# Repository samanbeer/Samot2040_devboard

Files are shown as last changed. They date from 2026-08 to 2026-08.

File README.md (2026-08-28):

# SamotPi2040 DevBoard



---

## 📌 Project Overview & Purpose

- **What is it?** A standalone development board based on the Raspberry Pi RP2040 dual-core ARM Cortex-M0+ processor.
- **What does it do?** It provides all essential supporting circuitry (power regulation, Li-Po 3.7V battery charging, automatic power source switching, high-speed crystal oscillator, SPI flash, USB termination, and ESD/pull-down configuration) to run MicroPython, CircuitPython, Arduino, or bare-metal C/C++ Pico SDK code.
- **Why does it exist?** It was created to explore custom PCB design from scratch, master 2-layer routing with fine-pitch QFN and 0402 components, and build a reliable, inexpensive, and customizable devboard for prototyping robotics and embedded electronics.

---

## Why I Made This Project

Because I wanted to design my own RP2040 board with my own design a to be able to say "I made this" with:
1. A modern **USB-C** connector
2. Integrate both **BOOT** and **RESET** switches directly on board to make flashing easy.
3. Provide a full 8MB high-speed SPI Flash storage for large CircuitPython scripts, assets, and datalogging.
4. Integrated **Li-Po 3.7V battery charging** (MCP73831) and **automatic power source switching** (BAT54C Schottky diode) for portable projects.

---

## Project Gallery

### 3D Render
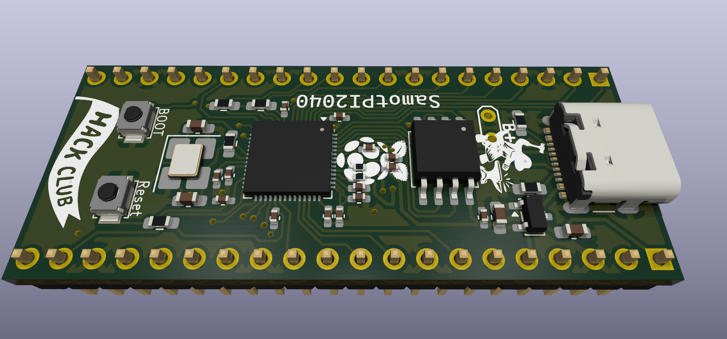
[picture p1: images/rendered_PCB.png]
Rendered PCB


### 3D Board View
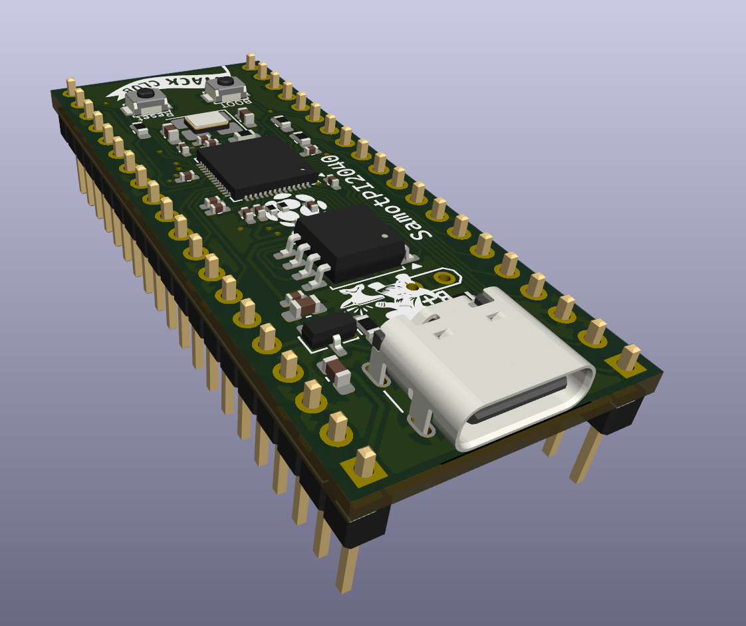
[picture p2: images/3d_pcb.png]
3D PCB


### PCB Layout & Routing
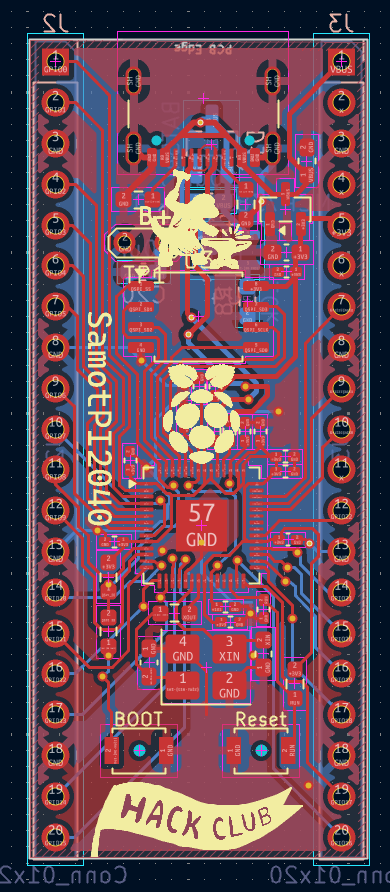
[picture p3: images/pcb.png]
PCB Layout


### Schematic
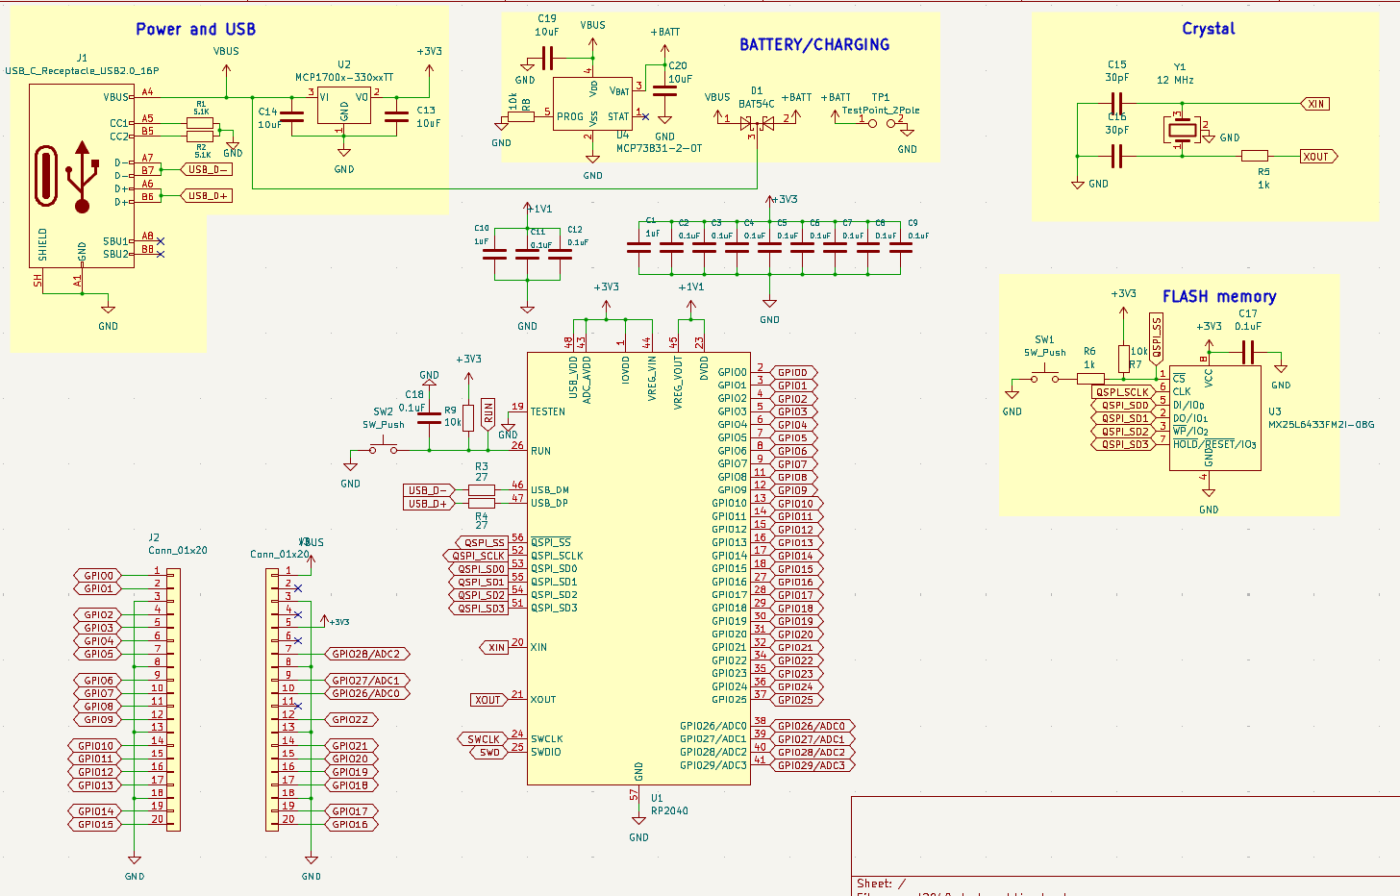
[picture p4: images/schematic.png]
Schematic Diagram


---

## Hardware Features & Specifications

| Feature | Specification |
| --- | --- |
| **Microcontroller** | Raspberry Pi RP2040 (Dual-core ARM Cortex-M0+ up to 133 MHz, 264 KB on-chip SRAM) |
| **Flash Memory** | 8 MB (64 Mbit) SPI Flash (Macronix MX25L6433FM2I-08G, SOIC-8) |
| **Power Input** | USB-C 5V VBUS or Li-Po / Li-Ion 3.7V Battery |
| **Battery Charger** | Microchip MCP73831-2-OT (Single-cell Li-Po/Li-Ion linear charge manager, 4.2V CC/CV) |
| **Power Multiplexing** | BAT54C dual Schottky barrier diode (automatic power source switching between USB and Battery) |
| **Voltage Regulation** | Microchip MCP1700T-3302E/TT (3.3V Low-Dropout Regulator, **250mA** output) |
| **Expansion / I/O** | 2x 1x20-pin 2.54mm pitch headers (breadboard compatible) |

---

##  Power Management & Battery Support

The board features a built-in power management circuit designed for both desktop development and portable battery-powered operation:

- **3.7V Li-Po / Li-Ion Battery Support:** Connect any standard 3.7V single-cell Lithium-Polymer (Li-Po) or Lithium-Ion (Li-Ion) battery to the `+BATT` and `GND` pins/pads.
- **Integrated Battery Charging:** The on-board **Microchip MCP73831** charge controller automatically charges the battery when connected to USB-C (5V VBUS) using constant current / constant voltage (CC/CV) up to 4.2V.
- **Automatic Power Source Switching:** A dual common-cathode Schottky diode (**BAT54C**) acts as an automatic power OR-ing switch. When USB-C is plugged in, the board runs directly from USB power while recharging the battery. When USB-C is disconnected, power seamlessly falls over to the battery without interruption or board resets.

---

## 🛠️ Step-by-Step Assembly Guide

> [!IMPORTANT]
> I recommend using HOT airflow station or hot plate for soldering because there are really small components like the main chip or 0402 capacitors/resistors

### Required Tools
- Hot air station / hot plate and soldering iron
- solder flux paste / pen and solder wick
- tweezers
- USB-C data cable

### Assembly Steps

1. **Solder the RP2040 chip:**
   - Apply a thin layer of solder paste to the center thermal pad and other pads.
   - Align first pin of the RP2040 chip using the silkscreen dot marker.
   - Reflow using hot air (~320°C–350°C) or hot plate. Make sure the chip is centered.
2. **Solder the Flash (U3), Voltage Regulator (U2), Charger (U4), and Diode (D1):**
   - Solder the MX25L6433 flash chip (SOIC-8), MCP1700 (SOT-23), MCP73831 charger (SOT-23-5), and BAT54C diode (SOT-23). You can do this with normal soldering iron and plenty of flux.
3. **Solder Passives (Resistors & Capacitors) and Crystal:**
   - Solder the small 0402 capacitors (C1–C12, C17, C18) close to the RP2040 power pins.
   - Solder the 0603 capacitors (C13, C14), crystal load capacitors (C15, C16), and resistors (R1–R7, R9).
   - Then carefully solder the 12 MHz crystal (Y1).
4. **Solder USB-C (J1):**
   - Align the 16-pin USB-C receptacle (GCT USB4085). Solder the through-hole shielding legs for mechanical strength, then use a iron tip with a lot of flux to solder the other pins.
5. **Solder buttons(SW1, SW2):**
   - Solder the swithces for BOOT and RESET.
6. **Double check :**
   - Inspect all solder joidnts under magnification for solder bridges or cold joints (especially on the RP2040 and USB-C).
   - Using a multimeter in continuity/resistance mode, verify that `VBUS` (5V), `3V3`, and `GND` are **not shorted**.
7. **Solder Pin Headers (J2, J3, ):**
   - Insert the 1x20 2.54mm male headers into a solderless breadboard to keep them perpendicular, place the PCB on top, and solder each pin.

---

##  How to Flash Firmware

The RP2040 has a built-in ROM bootloader that makes flashing firmware simple without requiring external programmers:

```mermaid
flowchart LR
    A["Hold BOOT"] --> B["Plug in USB-C"]
    B --> C["'RPI-RP2' Drive Appears"]
    C --> D["Drag & Drop .UF2 File"]
    D --> E["Auto Reboot & Run!"]
```

1. **Enter Bootloader Mode:**
   - Hold the **`BOOT`** button (SW1).
   - Connect the board to computer using a USB-C data cable 
   - Release the `BOOT` button.
3. **Flashing Firmware:**
   - Drag and drop your compiled **`.uf2`** firmware file onto the `RPI-RP2` drive that should appear on PC:
     - **MicroPython:** Download the [Official RP2040 MicroPython UF2](https://micropython.org/download/rp2-pico/).
     - **CircuitPython:** Download the [Adafruit CircuitPython RP2040 UF2](https://circuitpython.org/board/raspberry_pi_pico/).
     - **C/C++ SDK / Arduino:** Build your project using Arduino IDE (with Earle Philhower RP2040 core) or Pico SDK and drag the resulting `.uf2` file.
4. **Execution:**
   - Once the `.uf2` file finishes copying, the board will automatically dismount and execute the program immediately.

---

## BOM

> Import [`quickOrder_TME.csv`](quickOrder_TME.csv) directly to [TME.eu](https://tme.eu) for fast order.

| Qty | Value | Reference | Footprint | Where | Cost (USD) |
|:---:|:---|:---|:---|:---|:---:|
| 1 | **RP2040** | U1 | QFN-56-1EP (7x7mm, 0.4mm pitch) | [TME LINK](https://www.tme.eu/cz/details/sc0914-7/raspberry-pi-vestavene-systemy/raspberry-pi/ic-rp2040-rp2b2-t-r-500-7-reel/) | $1.02 |
| 1 | **MX25L6433FM2I-08G** (8MB Flash) | U3 | SOIC-8 (5.3x5.3mm, 1.27mm pitch) | [TME LINK](https://www.tme.eu/cz/details/mx25l6433fm2i-08g/pameti-flash-seriove/macronix-international/mx25l6433fm2i-08g-tube/) | $2.40 |
| 1 | **MCP1700T-3302E/TT** (3.3V LDO) | U2 | SOT-23 | [TME LINK](https://www.tme.eu/cz/details/mcp1700t-3302e_tt/stabilizatory-napeti-neregulovane-ldo/microchip-technology/) | $0.65 |
| 1 | **12 MHz Crystal** | Y1 | SMD 3225-4Pin (3.2x2.5mm) | [TME LINK](https://www.tme.eu/cz/details/abm8g-12.000mhz-18/resonators-and-generators/abracon/abm8g-12-000mhz-18-d2y-t/) | $0.39 |
| 1 | **USB-C Receptacle 16P** | J1 | GCT_USB4105 | [TME LINK](https://www.tme.eu/cz/details/usb4105-gf-a/konektory-usb-a-ieee1394/gct/) | $0.75 |
| 2 | **Tactile Switch SPST** | SW1, SW2 | SMD (Omron B3U-1000P-B) | [TME LINK](https://www.tme.eu/cz/details/b3u-1000pb/mikrospinace-tact/omron-electronic-components/b3u-1000p-b/) | $1.95 |
| 12 | **0.1 µF (100nF) 16V** | C2, C3, C4, C5, C6, C7, C8, C9, C11, C12, C17, C18 | C_0402 (1005 Metric) | [TME LINK](https://www.tme.eu/cz/details/grm155r71c104ka88d/kondenzatory-mlcc-smd/murata/) | $0.17 |
| 2 | **1 µF 25V** | C1, C10 | C_0402 (1005 Metric) | [TME LINK](https://www.tme.eu/cz/details/grm155r61e105ma12d/kondenzatory-mlcc-smd/murata/) | $0.095 |
| 4 | **10 µF 10V** | C13, C14, C19, C20 | C_0603 (1608 Metric) | [TME LINK](https://www.tme.eu/cz/details/lmk107bj106maltd/kondenzatory-mlcc-smd/taiyo-yuden/lmk107-bj106maltd/) | $0.60 |
| 2 | **27 pF 50V** | C15, C16 | C_0603 (1608 Metric) | [TME LINK](https://www.tme.eu/cz/details/cc0603jrnpo9270/kondenzatory-mlcc-smd/yageo/cc0603jrnpo9bn270/) | $0.043 |
| 2 | **27 Ω 1%** | R3, R4 | R_0402 (1005 Metric) | [TME LINK](https://www.tme.eu/cz/details/erj2rkf27r0x/rezistory-smd/panasonic/) | $0.25 |
| 2 | **5.1 kΩ 1%** | R1, R2 | R_0603 (1608 Metric) | [TME LINK](https://www.tme.eu/cz/details/wr06x5101ftl/rezistory-smd/walsin/) | $0.18 |
| 2 | **1 kΩ 1%** | R5, R6 | R_0603 (1608 Metric) | [TME LINK](https://www.tme.eu/cz/details/crcw06031k00fkea/rezistory-smd/vishay/) | $0.015 |
| 2 | **10 kΩ 1%** | R7, R8, R9 | R_0603 (1608 Metric) | [TME LINK](https://www.tme.eu/cz/details/rc0603jr-0710k/rezistory-smd/yageo/rc0603jr-0710kl/) | $0.15 |
| 2 | **Pin Header 1x20 (2.54mm)** | J2, J3 | PinHeader_1x20_P2.54mm_Vertical | [TME LINK](https://www.tme.eu/cz/details/sl8.20z/konektory-hrebinky/fischer-elektronik/10057879/) | $4.5(I dont need these. Already own) |
| 1 | **MCP73831-2-OT** | U4 | SOT-23-5_HandSoldering | [TME LINK](https://www.tme.eu/cz/details/mcp73831t-2aci_ot/kontrolery-baterii-a-akumulat-obvody/microchip-technology/) | ~$0.75 |
| 1 | **BAT54C** | D1 | SOT-23_Handsoldering | [TME LINK](https://www.tme.eu/cz/details/bat54c-aks/diody-schottky-smd/akyga-semi/aks0016/) | ~$0.07 |
| 1 | **Li-Po 3.7V Battery** | - | - | [TME LINK](https://www.tme.eu/cz/details/aky-lp401235/akumulatory/akyga-battery/aky0475/) | ~$5.7 |
| 1 | **PCB ** | PCB | 2-layer FR-4 (1.6mm, ENIG/HASL) | [JLCPCB](https://jlcpcb.com) | ~$13.45 |
| - | **Estimated Shipping** | - | - | - | ~$8.21 |
| **Total** | | | | | **~$41,34** |

### JLCPCB Cart:

<p align="center">
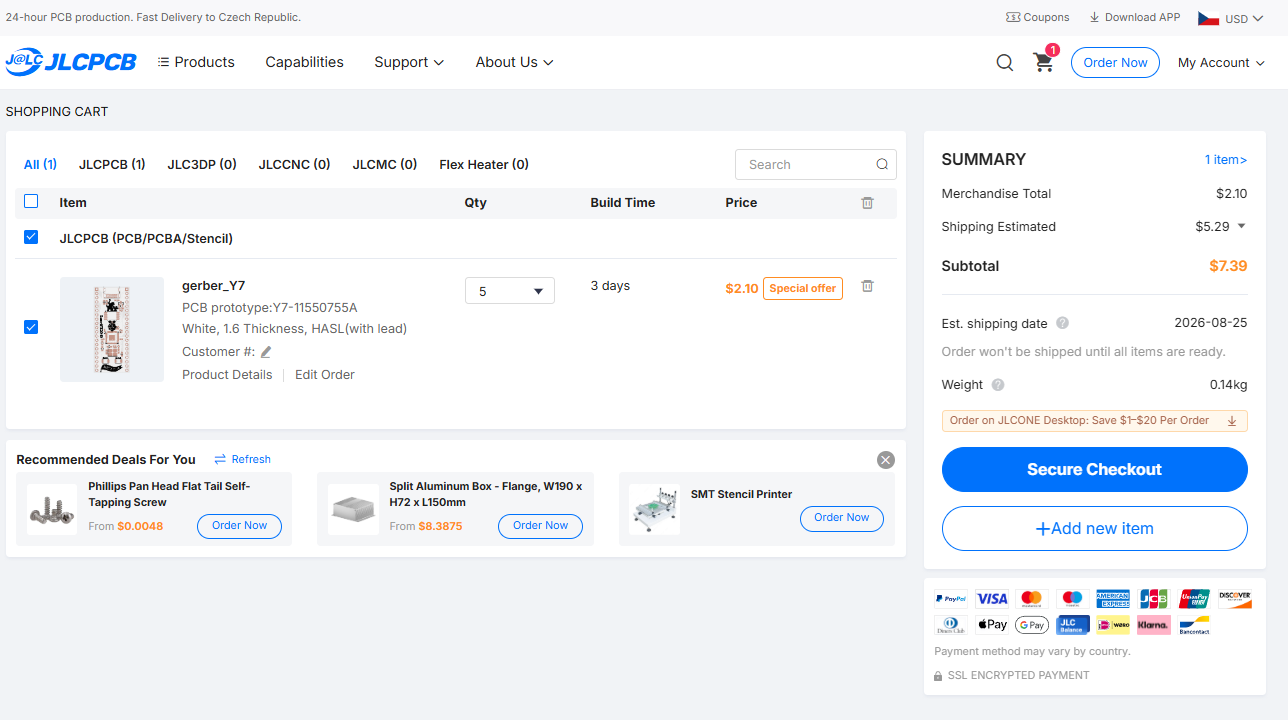
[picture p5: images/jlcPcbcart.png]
JLCPCB Cart 1
  
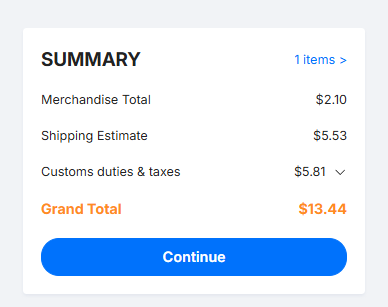
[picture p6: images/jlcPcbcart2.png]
JLCPCB Cart 2
  
</p>

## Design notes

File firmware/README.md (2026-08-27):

You can choose between Arduino Code and pre compiled firmware .uf2 which you can just drah and drop into RP2040 for quick check.

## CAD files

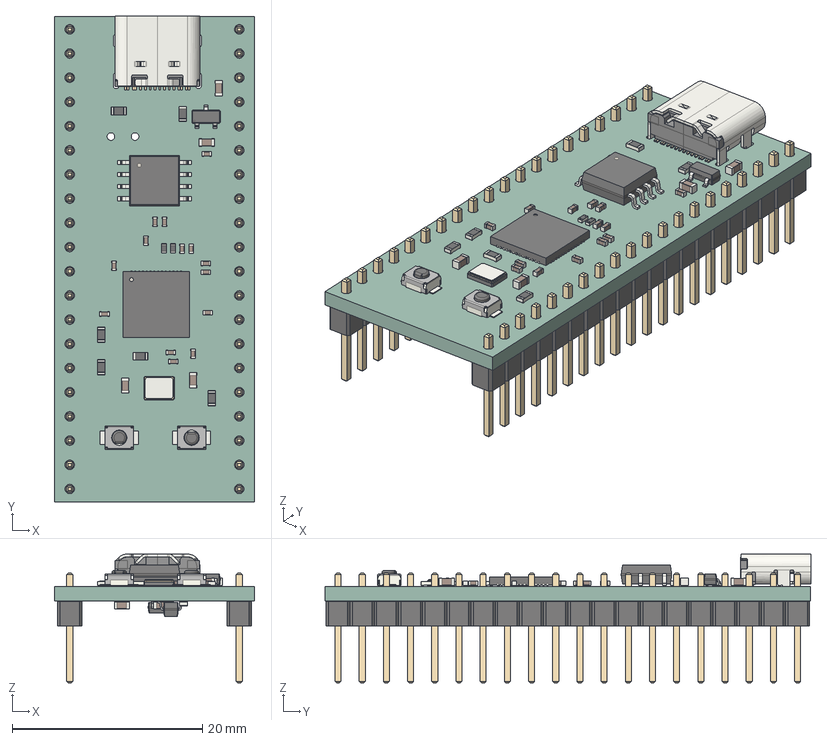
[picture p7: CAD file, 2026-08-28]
PCB.step
21.0 x 51.0 x 13.5 mm
C_0402_1005Metric x 14
C_0603_1608Metric x 6
R_0603_1608Metric x 7
SOT-23 x 2
USB_C_Receptacle_16P_TopMnt_Horizontal_GCT_USB4105-xx-A
SOIC-8_5.3x5.3mm_P1.27mm
R_0402_1005Metric x 2
SW_SPST_B3U-1000P-B x 2
Crystal_SMD_3225-4Pin_3.2x2.5mm
QFN-56-1EP_7x7mm_P0.4mm_EP3.2x3.2mm
PinHeader_1x20_P254mm_Vertical x 2
SOT-23-5
samot2040_devboard_PCB

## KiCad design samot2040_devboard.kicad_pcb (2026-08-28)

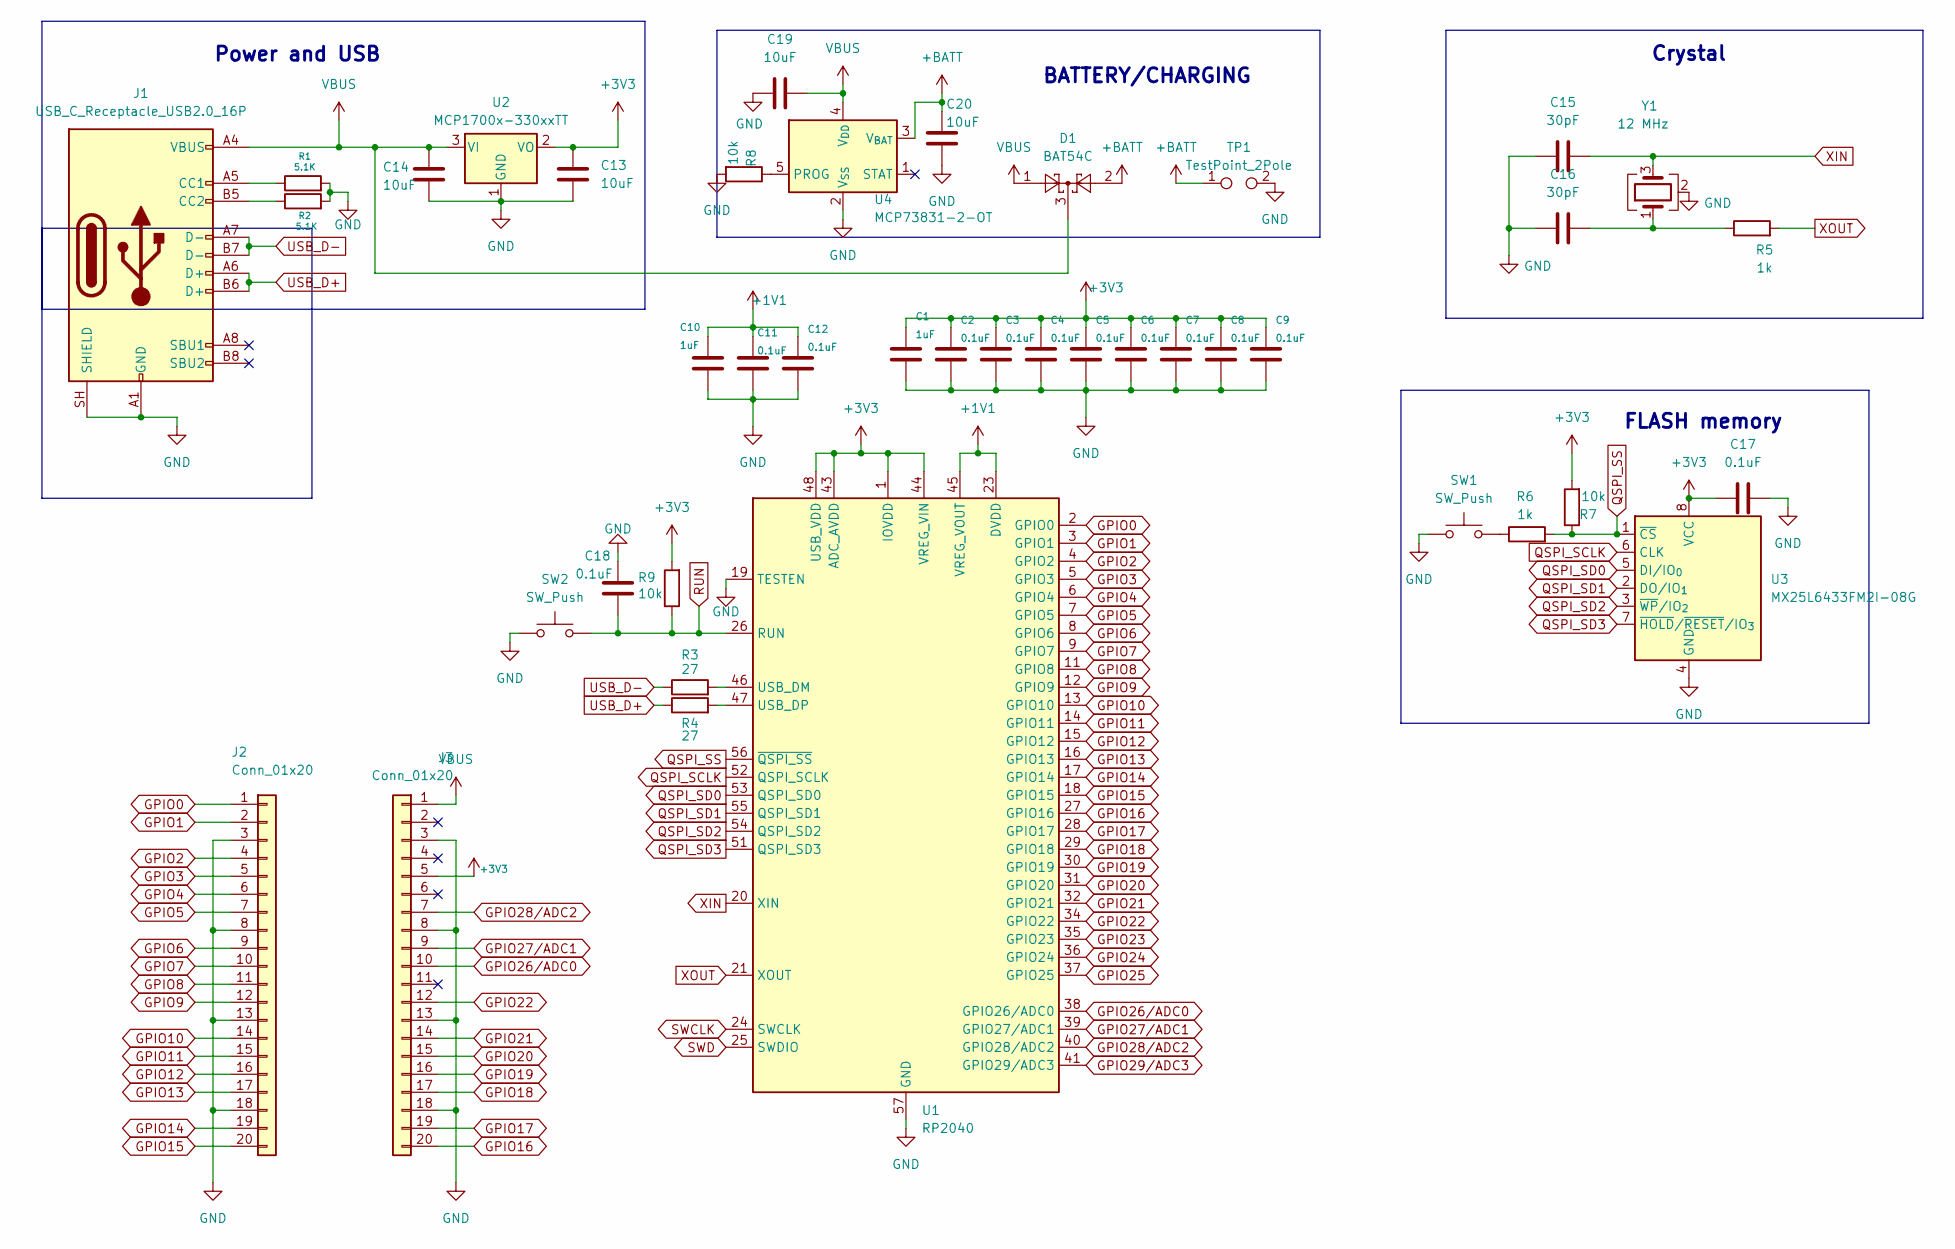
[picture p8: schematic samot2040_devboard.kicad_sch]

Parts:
C1, C10: 1uF; C_0402_1005Metric_Pad0.74x0.62mm_HandSolder
C2, C3, C4, C5, C6, C7, C8, C9, C11, C12, C17, C18: 0.1uF; C_0402_1005Metric_Pad0.74x0.62mm_HandSolder
C13, C14, C19, C20: 10uF; C_0603_1608Metric_Pad1.08x0.95mm_HandSolder
C15, C16: 30pF; C_0603_1608Metric_Pad1.08x0.95mm_HandSolder
D1: BAT54C; SOT-23_Handsoldering
J1: USB_C_Receptacle_USB2.0_16P; USB_C_Receptacle_GCT_USB4105-xx-A_16P_TopMnt_Horizontal
J2, J3: Conn_01x20; PinHeader_1x20_P2.54mm_Vertical
R1, R2: 5.1K; R_0603_1608Metric_Pad0.98x0.95mm_HandSolder
R3, R4: 27; R_0402_1005Metric_Pad0.72x0.64mm_HandSolder
R5, R6: 1k; R_0603_1608Metric_Pad0.98x0.95mm_HandSolder
R7, R8, R9: 10k; R_0603_1608Metric_Pad0.98x0.95mm_HandSolder
SW1, SW2: SW_Push; SW_SPST_B3U-1000P-B
TP1: TestPoint_2Pole; TestPoint_2Pads_Pitch2.54mm_Drill0.8mm
U1: RP2040; QFN-56-1EP_7x7mm_P0.4mm_EP3.2x3.2mm
U2: MCP1700x-330xxTT; SOT-23
U3: MX25L6433FM2I-08G; SOIC-8_5.3x5.3mm_P1.27mm
U4: MCP73831-2-OT; SOT-23-5_HandSoldering
Y1: 12 MHz; Crystal_SMD_3225-4Pin_3.2x2.5mm_HandSoldering

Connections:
+1V1: C10.1, C11.1, C12.1, U1.23 (DVDD), U1.45 (VREG_VOUT), U1.50 (DVDD)
+3V3: C1.1, C2.1, C3.1, C4.1, C5.1, C6.1, C7.1, C8.1, C9.1, C13.1, C17.1, J3.5, R7.2, R9.2, U1.1 (IOVDD), U1.10 (IOVDD), U1.22 (IOVDD), U1.33 (IOVDD), U1.42 (IOVDD), U1.43 (ADC_AVDD), U1.44 (VREG_VIN), U1.48 (USB_VDD), U1.49 (IOVDD), U2.2 (VO), U3.8 (VCC)
+BATT: C20.2, D1.2, TP1.1, U4.3 (V_{BAT})
GND: C1.2, C2.2, C3.2, C4.2, C5.2, C6.2, C7.2, C8.2, C9.2, C10.2, C11.2, C12.2, C13.2, C14.2, C15.1, C16.1, C17.2, C18.1, C19.1, C20.1, J1.A1 (GND), J1.A12 (GND), J1.B1 (GND), J1.B12 (GND), J1.SH (SHIELD), J2.3, J2.8, J2.13, J2.18, J3.3, J3.8, J3.13, J3.18, R1.2, R2.2, R8.2, SW1.1, SW2.1, TP1.2, U1.19 (TESTEN), U1.57 (GND), U2.1 (GND), U3.4 (GND), U4.2 (V_{SS}), Y1.2 (G), Y1.4 (G)
GPIO0: J2.1, U1.2 (GPIO0)
GPIO1: J2.2, U1.3 (GPIO1)
GPIO2: J2.4, U1.4 (GPIO2)
GPIO3: J2.5, U1.5 (GPIO3)
GPIO4: J2.6, U1.6 (GPIO4)
GPIO5: J2.7, U1.7 (GPIO5)
GPIO6: J2.9, U1.8 (GPIO6)
GPIO7: J2.10, U1.9 (GPIO7)
GPIO8: J2.11, U1.11 (GPIO8)
GPIO9: J2.12, U1.12 (GPIO9)
GPIO10: J2.14, U1.13 (GPIO10)
GPIO11: J2.15, U1.14 (GPIO11)
GPIO12: J2.16, U1.15 (GPIO12)
GPIO13: J2.17, U1.16 (GPIO13)
GPIO14: J2.19, U1.17 (GPIO14)
GPIO15: J2.20, U1.18 (GPIO15)
GPIO16: J3.20, U1.27 (GPIO16)
GPIO17: J3.19, U1.28 (GPIO17)
GPIO18: J3.17, U1.29 (GPIO18)
GPIO19: J3.16, U1.30 (GPIO19)
GPIO20: J3.15, U1.31 (GPIO20)
GPIO21: J3.14, U1.32 (GPIO21)
GPIO22: J3.12, U1.34 (GPIO22)
GPIO23: U1.35 (GPIO23)
GPIO24: U1.36 (GPIO24)
GPIO25: U1.37 (GPIO25)
GPIO26/ADC0: J3.10, U1.38 (GPIO26/ADC0)
GPIO27/ADC1: J3.9, U1.39 (GPIO27/ADC1)
GPIO28/ADC2: J3.7, U1.40 (GPIO28/ADC2)
GPIO29/ADC3: U1.41 (GPIO29/ADC3)
unnamed: C16.2, R5.1, Y1.1
unnamed: J1.A5 (CC1), R1.1
unnamed: J1.B5 (CC2), R2.1
unnamed: R6.1, SW1.2
unnamed: R3.2, U1.46 (USB_DM)
unnamed: R4.2, U1.47 (USB_DP)
unnamed: R8.1, U4.5 (PROG)
QSPI_SCLK: U1.52 (QSPI_SCLK), U3.6 (CLK)
QSPI_SD0: U1.53 (QSPI_SD0), U3.5 (DI/IO_{0})
QSPI_SD1: U1.55 (QSPI_SD1), U3.2 (DO/IO_{1})
QSPI_SD2: U1.54 (QSPI_SD2), U3.3 (~WP/IO_{2})
QSPI_SD3: U1.51 (QSPI_SD3), U3.7 (~HOLD/~RESET/IO_{3})
QSPI_SS: R6.2, R7.1, U1.56 (~QSPI_SS), U3.1 (~CS)
RUN: C18.2, R9.1, SW2.2, U1.26 (RUN)
SWCLK: U1.24 (SWCLK)
SWD: U1.25 (SWDIO)
USB_D+: J1.A6 (D+), J1.B6 (D+), R4.1
USB_D-: J1.A7 (D-), J1.B7 (D-), R3.1
VBUS: C14.1, C19.2, D1.1, D1.3, J1.A4 (VBUS), J1.A9 (VBUS), J1.B4 (VBUS), J1.B9 (VBUS), J3.1, U2.3 (VI), U4.4 (V_{DD})
XIN: C15.2, U1.20 (XIN), Y1.3
XOUT: R5.2, U1.21 (XOUT)

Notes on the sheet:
Power and USB
Crystal
BATTERY/CHARGING
FLASH memory

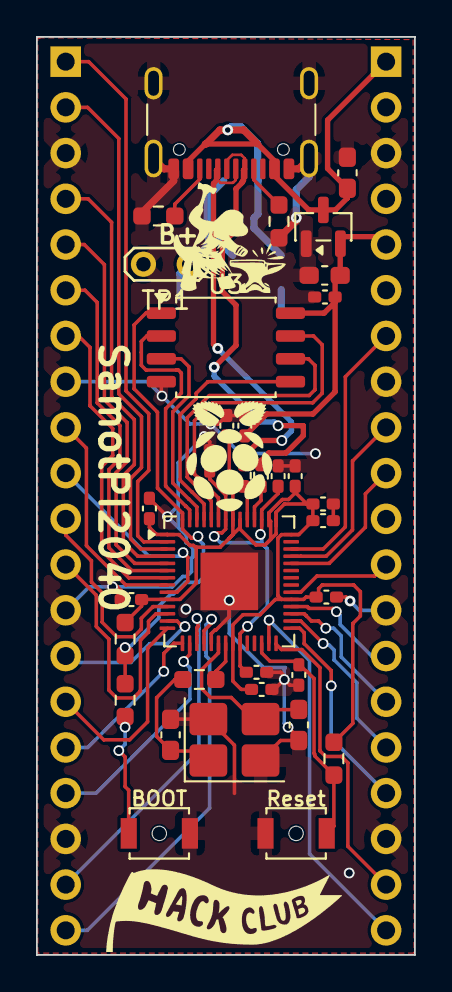
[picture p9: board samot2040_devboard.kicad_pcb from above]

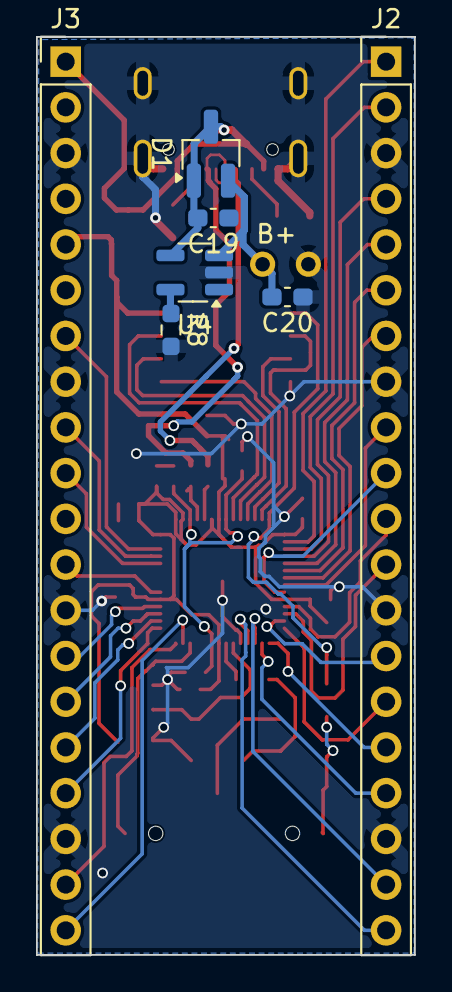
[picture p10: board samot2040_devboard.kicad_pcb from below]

Board: 2 copper layers, 21.0 x 51.0 mm, 41 parts (7 on the bottom side), 49 nets.

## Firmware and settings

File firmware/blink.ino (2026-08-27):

int led = LED_BUILTIN;

void setup() {
  // Some boards work best if we also make a serial connection
  Serial.begin(115200);

  // set LED to be an output pin
  pinMode(led, OUTPUT);
}

void loop() {
  // Say hi!
  Serial.println("Hello!");
  
  digitalWrite(led, HIGH);   // turn the LED on (HIGH is the voltage level)
  delay(500);                // wait for a half second
  digitalWrite(led, LOW);    // turn the LED off by making the voltage LOW
  delay(500);                // wait for a half second
}

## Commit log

2026-08-21 Shematic done with footprints and created and sourced BOM
    [bom_KCexport.csv, fastOrder_BOM.csv, samot2040_devboard.kicad_pcb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]
2026-08-26 Update USB-C connector
    [samot2040_devboard-B_Cu.gbr, samot2040_devboard-B_Mask.gbr, samot2040_devboard-B_Paste.gbr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]
2026-08-26 update BOM and quickorder.csv for new USB-C
    [quickOrder_TME.csv]
2026-08-27 added firmware
    [samot2040_devboard.kicad_sch]
2026-08-28 added battery support and charging
    [PCB.step, quickOrder_TME.csv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]
